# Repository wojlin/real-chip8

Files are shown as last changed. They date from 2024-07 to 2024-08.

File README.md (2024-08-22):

# CHIP8 Machine

## Info:

The CHIP8 Machine is a modern recreation of a vintage 8-bit virtual machine designed to play classic CHIP8 games. Originally developed in the 1970s, CHIP8 was a simple, yet powerful, programming environment that allowed developers to create games and programs with minimal hardware requirements. This project brings the CHIP8 experience to life by building a physical device that runs these vintage games on a custom-made machine, complete with a tactile keyboard, LED display, and an SD card for game storage.

The CHIP8 Machine is perfect for enthusiasts of retro computing and gaming, as well as those interested in DIY electronics projects. It provides a hands-on way to explore the origins of digital entertainment while learning about hardware assembly, 3D printing, and embedded programming.

## Overview:

This guide provides detailed instructions on how to build and set up a CHIP8 machine, including the parts needed, 3D printing instructions, wiring, and software installation.

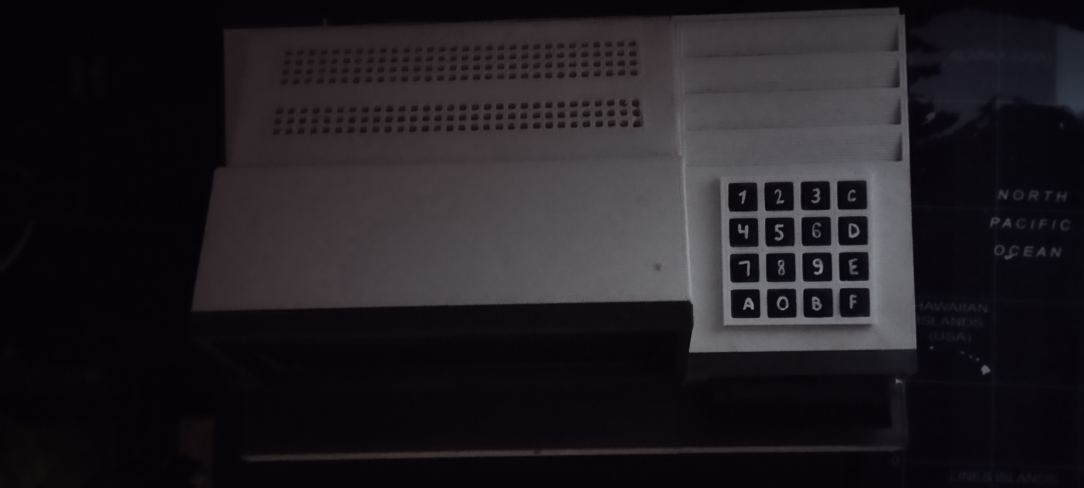
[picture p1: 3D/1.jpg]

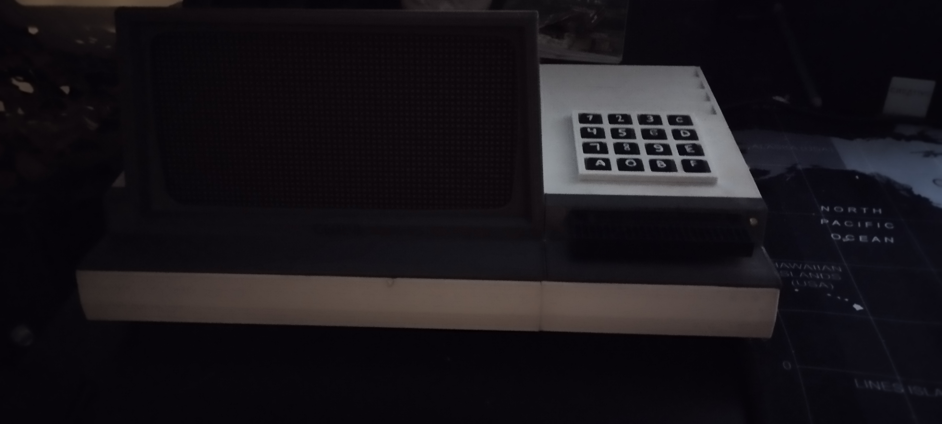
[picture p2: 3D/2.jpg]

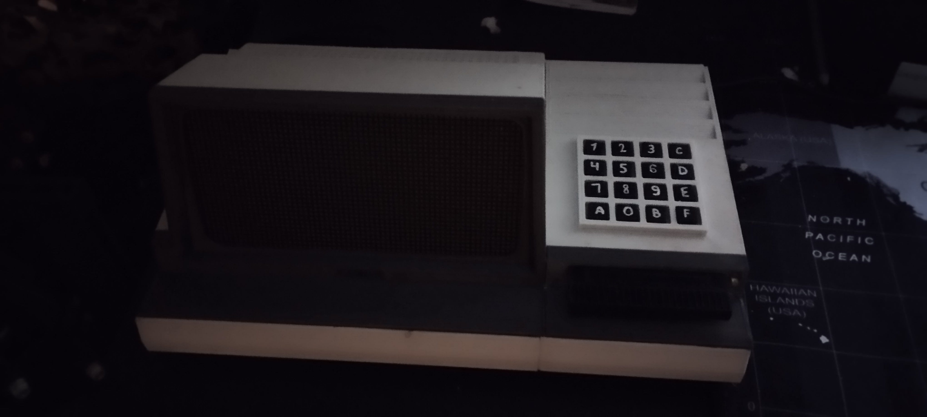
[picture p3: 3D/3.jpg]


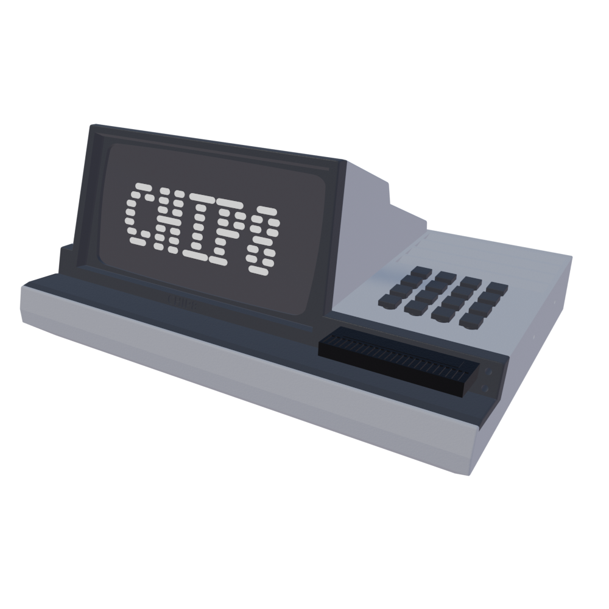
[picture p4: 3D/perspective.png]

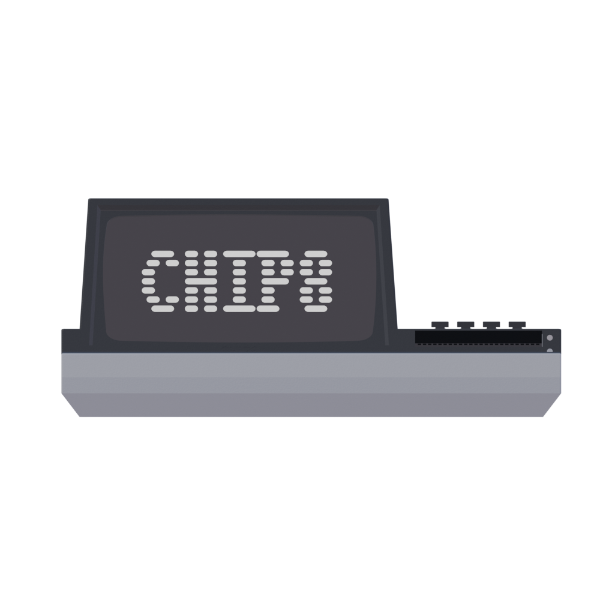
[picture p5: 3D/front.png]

<br>
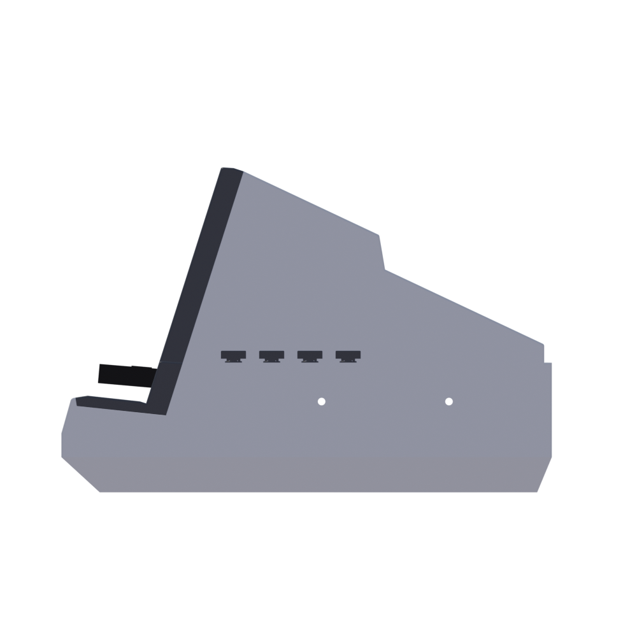
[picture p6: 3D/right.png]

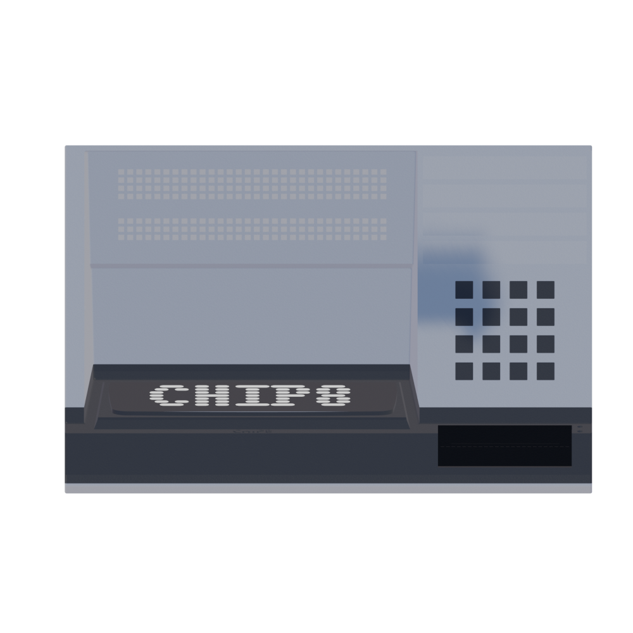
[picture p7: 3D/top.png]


## Documentation:

### Parts List:

You'll need the following components to build the CHIP8 machine:

| Part | Quantity | Link |
|---|---|---|
| 5V 4A power supply | 1 | [Link](https://botland.store/socket-power-supply/8850-power-supply-5v-4a-dc-55-25-plug-5903351242530.html) |
| 12x12mm tact switch with cap | 16 | [Link](https://botland.store/tact-switch/11138-tact-switch-12x12mm-cap-black-5-pieces-5904422307530.html) |
| Micro SD card reader | 1 | [Link](https://botland.store/memory-cards-accessories/8230-micro-sd-card-reader-module-5904422311278.html) |
| 3mm yellow LED | 1 | [Link](https://botland.store/leds/19988-led-3mm-yellow-10pcs-justpi-5904422328764.html) |
| 3mm red LED | 1 | [Link](https://botland.store/leds/19989-led-3mm-red-10pcs-justpi-5904422328771.html) |
| 64x32px 2.5mm Waveshare matrix display | 1 | [Link](https://www.waveshare.com/rgb-matrix-p2.5-64x32.htm) |
| Arduino Mega 2560 | 1 | [Link](https://botland.store/arduino-compatible-boards-dfrobot/2685-dfrobot-mega-2560-v32-compatible-with-arduino-6959420922345.html) |
| Arduino Uno | 1 | [Link](https://botland.store/arduino-basic-boards/1060-arduino-uno-rev3-module-a000066-7630049200050.html) |
| 5mm power switch | 1 | |

**Additional Tools & Materials:**

- Wires
- Soldering tools
- Polishing papers
- Clips
- Screwdriver
- Nail polish remover (optional, for fitting parts)

### Printing & Assembly:

1. **3D Printing:**

   - Find the print files in the `3D/stl` directory.
   - Print the following parts:

    | File               | Color | Quantity |
    |--------------------|-------|----------|
    | display_cover.stl  | Gray  | 1        |
    | keyboard_cover.stl | Gray  | 1        |
    | screw_2x.stl       | Gray  | 2        |
    | screw_4x.stl       | Gray  | 4        |
    | display_mount.stl  | White | 1        |
    | keyboard_mount.stl | White | 1        |
    | keyboard_holder.stl| White | 1        |
    | bottom.stl         | White | 1        |
    | bottom_right.stl   | White | 1        |
    | joiner_3mm_2x.stl  | White | 2        |
    | joiner_5mm_2x.stl  | White | 2        |
    | cartridge.stl      | Black | 1 or more|

    **Required Filament:**

    - White: 0.7 kg
    - Gray: 0.2 kg
    - Black: 0.05 kg

2. **Assembly:**

   - Use the `3D/mode/chip8.blend` file in Blender to visualize the assembly process.
   - Assemble the printed parts (use polishing paper, tools, and nail polish remover for better fitting).
   - Apply a protective coat or paint if desired.
   - Use 4x mm bolts to mount the bottom part with the top parts.
   - Insert the 16x 12x12mm tact switches into the `keyboard_mount.stl` part (use glue to secure them tightly).
   - Place the 3mm yellow LED in the upper hole and the 3mm red LED in the lower hole of `keyboard_mount.stl` (use glue).
   - Insert an OTG USB cable into the cartridge hole in `keyboard_mount.stl` (use glue).
   - Mount the 64x32px RGB matrix display into the `display_mount.stl` (use glue to secure it tightly).
   - Place the SD card reader inside the `cartridge.stl`.
   - Print labels on standard paper and glue them onto the tact switch caps using the following layout:

     | | | | |
     |-|-|-|-|
     |1|2|3|C|
     |4|5|6|D|
     |7|8|9|E|
     |A|0|B|F|

### Wiring:

1. **Arduino Mega Connections:**

    | Pin | Connected To   |
    |-----|----------------|
    | rx3 | Arduino Uno tx  |
    | tx3 | Arduino Uno rx  |
    | A0  | Matrix-A        |
    | A1  | Matrix-B        |
    | A2  | Matrix-C        |
    | A3  | Matrix-D        |
    | 9   | Matrix-OE       |
    | 10  | Matrix-LAT      |
    | 11  | Matrix-CLK      |
    | 24  | Matrix-R1       |
    | 25  | Matrix-G1       |
    | 26  | Matrix-B1       |
    | 27  | Matrix-R2       |
    | 28  | Matrix-G2       |
    | 29  | Matrix-B2       |
    | 32  | Buzzer-sig      |
    | 34  | Power LED+      |
    | 35  | Signal LED+     |
    | 42  | C1              |
    | 43  | C2              |
    | 44  | C3              |
    | 45  | C4              |
    | 48  | R1              |
    | 49  | R2              |
    | 50  | R3              |
    | 51  | R4              |
    | 5V  | Buzzer 5V, Arduino Uno 5V  |
    | GND | Power LED-, Signal LED-, Buzzer GND, Matrix GND1-5, Arduino Uno GND |

2. **Arduino Uno Connections:**

    | Pin | Connected To   |
    |-----|----------------|
    | 5V  | Reader-5V      |
    | GND | Reader-GND     |
    | 10  | Reader-CS      |
    | 11  | Reader-MOSI    |
    | 12  | Reader-MISO    |
    | 13  | Reader-SCK     |
    | tx  | Arduino Mega rx|
    | rx  | Arduino Mega tx|

3. **Other Connections:**

    - Insert the Arduino Mega and Arduino Uno into the `bottom.stl` part.
    - Insert the 5V 4A power supply through the first hole in the `bottom.stl` part.
    - Insert the power switch through the second hole in the `bottom.stl` part.

### Software Installation:

1. **Preparing the SD Card:**

   - Format the SD card to the FAT file system and ensure its label is "chip8". If you want to use a different label, update the name in the `runtime/runtime.py` file.
   - Copy the CHIP8 ROMs you want to use onto the SD card (sample ROMs can be found in the `samples` directory).
   - Ensure that only `.ch8` files are on the card (remove any system-generated files like `trash`, `volume info`, etc.).

2. **Cloning the Repository:**

   - Clone the repository:

     ```bash
     git clone git@github.com:wojlin/real-chip8.git
     ```

3. **Installing Arduino IDE:**

   - Download and install the Arduino IDE from [here](https://www.arduino.cc/en/software).

4. **Uploading the Code:**

   - Plug the machine into the 5V

 4A socket (ensure the power supply is turned on before connecting the USB cable).
   - Open `sd/sd.ino` in the Arduino IDE.
   - Upload `sd.ino` to the Arduino Uno.
   - Open `emulator/emulator.ino` in the Arduino IDE.
   - Upload `emulator.ino` to the Arduino Mega.
   - Unplug the USB cable, mount the bottom part of the machine with the top, and secure it with screws.

### Troubleshooting:

1. Ensure the SD card is formatted to FAT.
2. Verify that the SD card name is "chip8".
3. Check that the files on the SD card are in DOS 8.3 format.

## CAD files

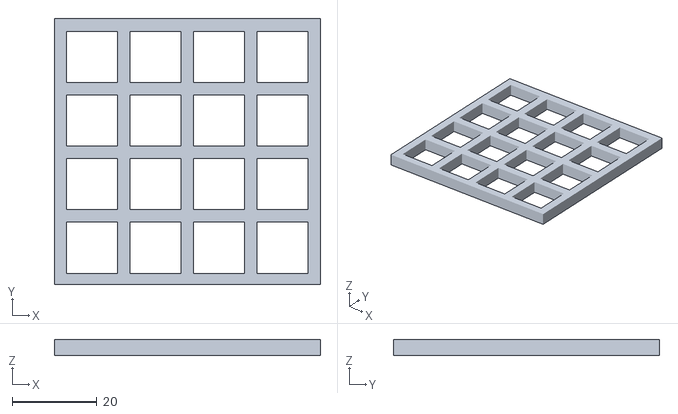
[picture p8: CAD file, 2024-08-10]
3D/stl/keyboard_holder.stl
62.8 x 62.8 x 3.83

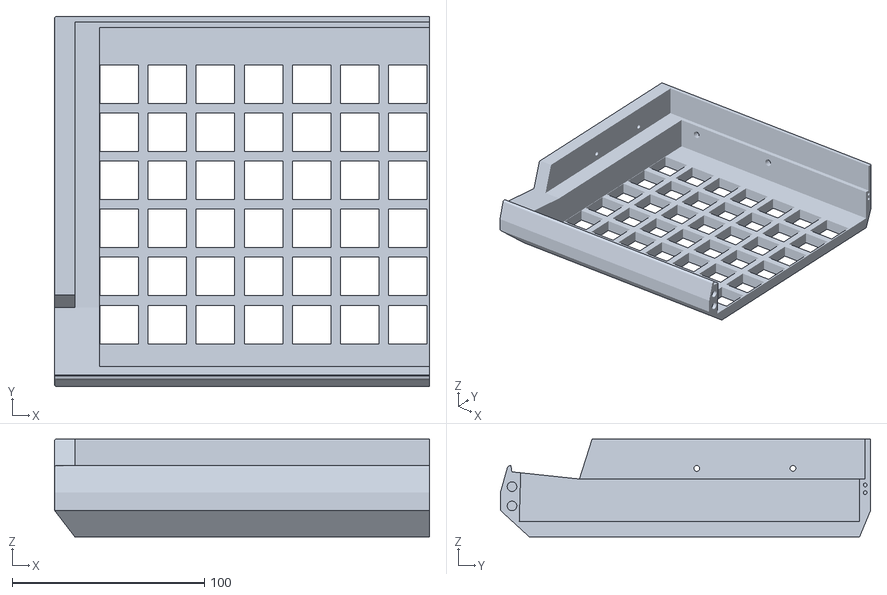
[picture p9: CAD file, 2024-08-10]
3D/stl/bottom.stl
194.9 x 192.5 x 50.9

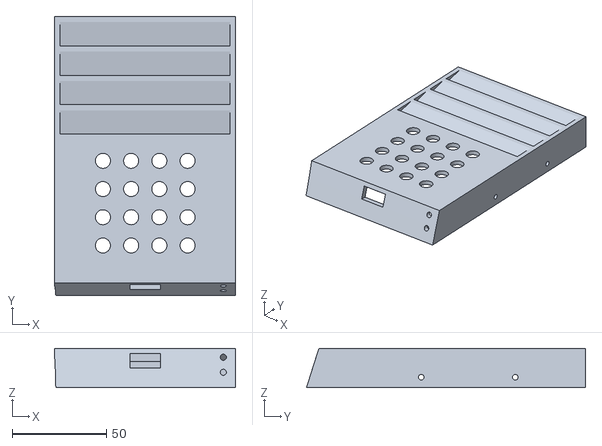
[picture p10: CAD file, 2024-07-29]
3D/stl/keyboard_mount.stl
96.5 x 148.3 x 20.7

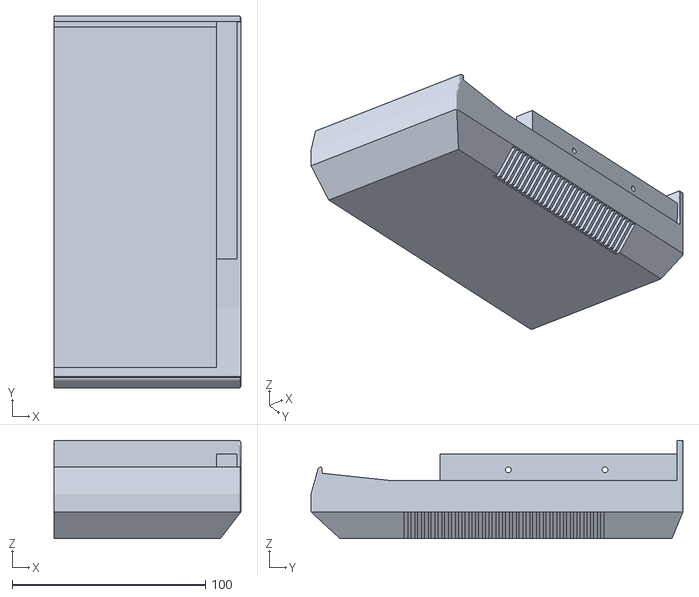
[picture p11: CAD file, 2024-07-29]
3D/stl/bottom_right.stl
96.6 x 192.5 x 50.9

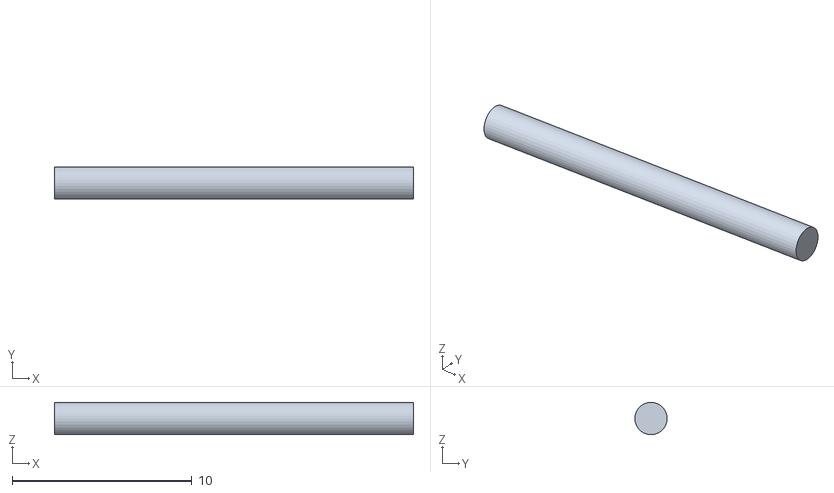
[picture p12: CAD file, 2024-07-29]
3D/stl/joiner_3mm_2x.stl
20.0 x 1.80 x 1.80

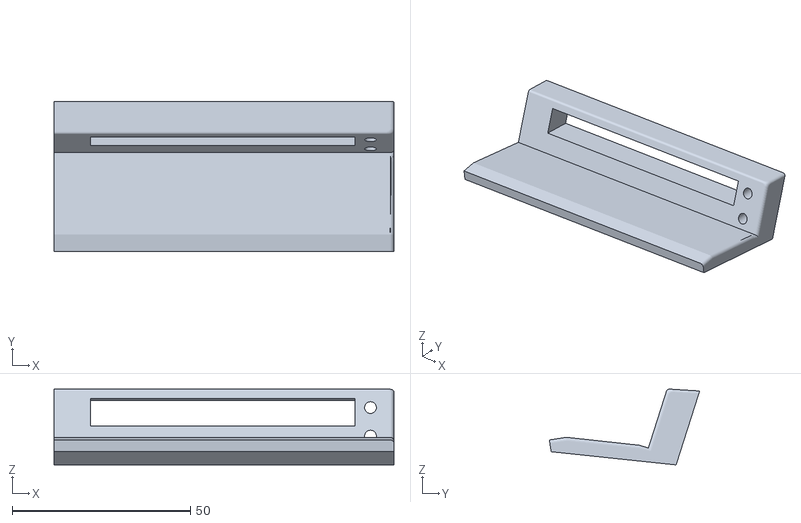
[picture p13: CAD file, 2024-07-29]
3D/stl/keyboard_cover.stl
95.4 x 42.2 x 21.3

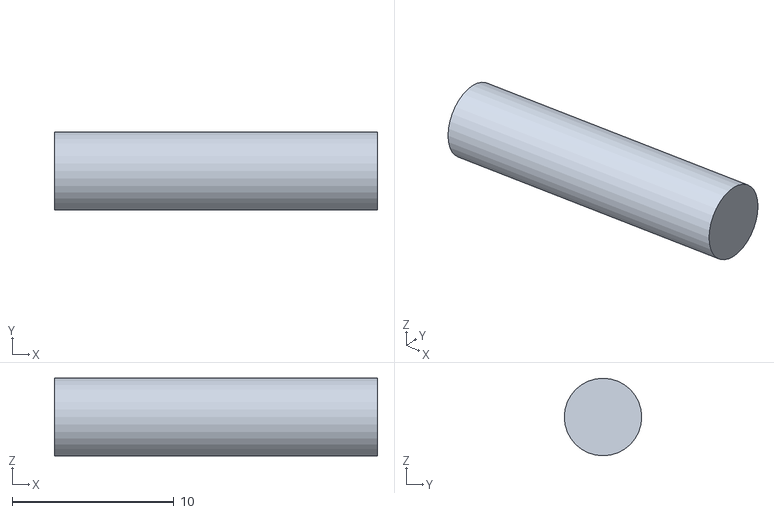
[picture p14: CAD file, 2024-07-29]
3D/stl/joiner_5mm_2x.stl
20.0 x 4.80 x 4.80

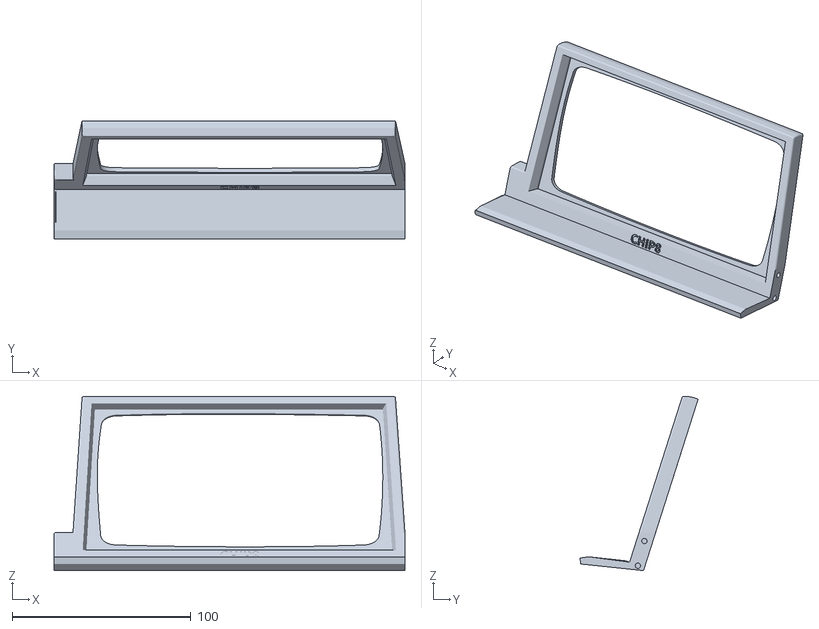
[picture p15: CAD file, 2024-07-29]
3D/stl/display_cover.stl
196.1 x 66.1 x 97.4

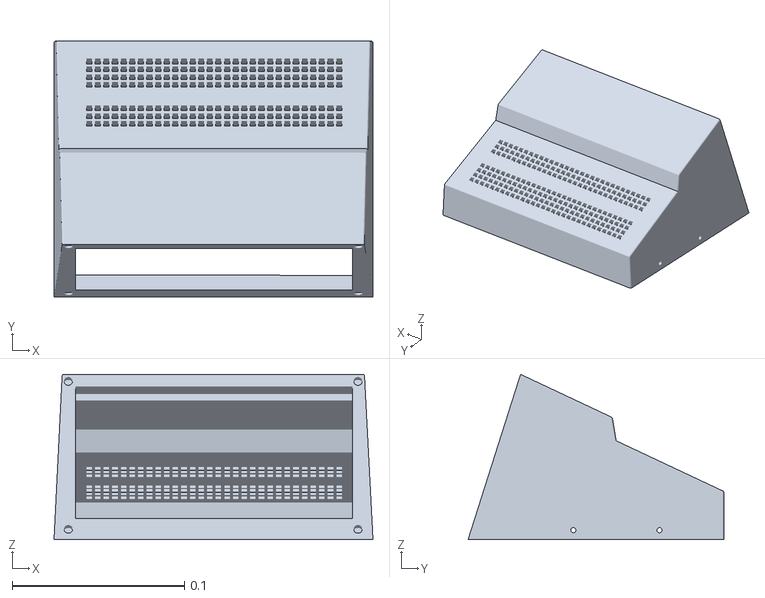
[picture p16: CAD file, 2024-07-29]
3D/stl/display_mount.stl
0.185 x 0.148 x 0.0959

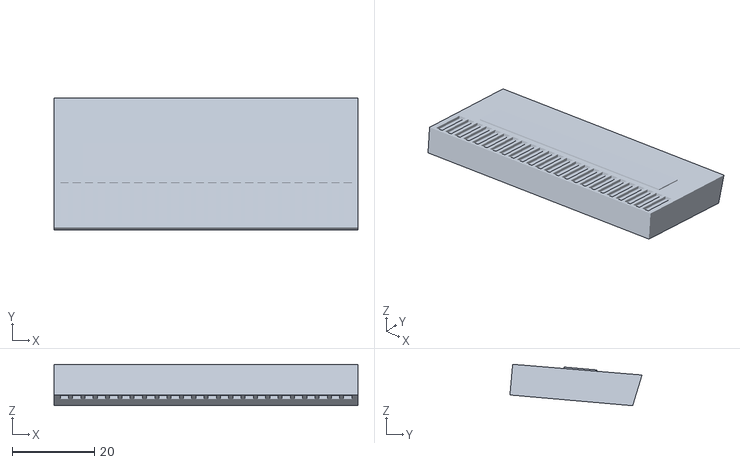
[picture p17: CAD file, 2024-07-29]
3D/stl/cartridge.stl
74.0 x 32.2 x 10.1

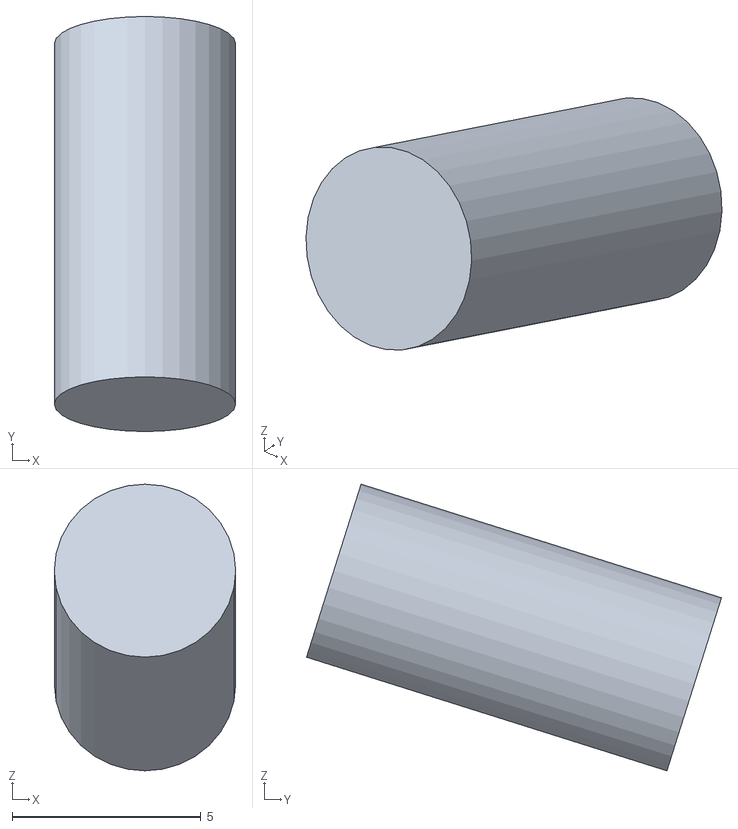
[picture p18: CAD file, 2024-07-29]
3D/stl/screw_4x.stl
4.80 x 11.0 x 7.58

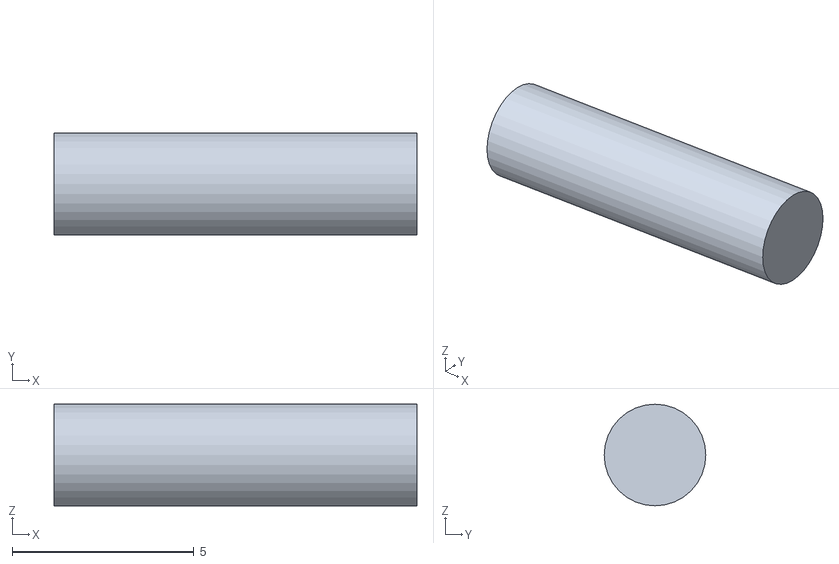
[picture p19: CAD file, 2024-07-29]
3D/stl/screw_2x.stl
10.0 x 2.80 x 2.80

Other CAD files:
3D/model/chip8.blend

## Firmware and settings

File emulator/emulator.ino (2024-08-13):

#include <Arduino.h>
#include <SPI.h>
#include "chip8-keypad.h"
#include "chip8-leds.h"
#include "chip8-buzzer.h"
#include "chip8.h"

#include "RGBmatrixPanel.h"
#include "Adafruit_GFX.h"
#include "bit_bmp.h"
#include "fonts.h"

#include <string.h>
#include <stdlib.h>

#include "Fonts/Picopixel.h"

#define CLK 11 
#define OE   9
#define LAT 10
#define A   A0
#define B   A1
#define C   A2
#define D   A3

RGBmatrixPanel matrix(A, B, C, D, CLK, LAT, OE, false, 64);
GFXcanvas1 canvas(64, 32);

//uint16_t high = matrix.ColorHSV(0,0,0,false);
//uint16_t low = matrix.ColorHSV(1100,155,80,false);

uint16_t high = matrix.ColorHSV(0,0,40,false);
uint16_t low = matrix.ColorHSV(0,0,0,false);

const uint8_t chip_select_reader_pin = 53;
const uint8_t buzzer_pin = 32;
const uint8_t power_led_pin = 34;
const uint8_t signal_led_pin = 35;
const uint8_t input_pins[] = {42, 43, 44, 45}; // Input pins (columns)
const uint8_t output_pins[] = {48, 49, 46, 47}; // Output pins (rows)
const uint8_t num_inputs = sizeof(input_pins) / sizeof(input_pins[0]); // Number of input pins (columns)
const uint8_t num_outputs = sizeof(output_pins) / sizeof(output_pins[0]); // Number of output pins (rows)



uint8_t file_count = 0;
const int BUFFER_SIZE = 200; // Size of the buffer to store received data
char received_data[BUFFER_SIZE]; // Buffer to store received data

#define MAX_FILES 20   // Maximum number of files
#define MAX_FILENAME_LENGTH 50  // Maximum length of each filename

char file_array[MAX_FILES][MAX_FILENAME_LENGTH]; // Adjust the size of the array according to the expected number and size of files


bool sd_plugged = false;
bool file_selected = false;
bool game_finished = false;

int current_file = 0;
int files_in_panel = 4; // Number of filenames that fit into the screen
int program_size;

void(* resetFunc) (void) = 0; //declare reset function @ address 0

void screen_setup()
{
  matrix.begin();
}


void screen_clear()
{
  matrix.fillRect(0, 0, matrix.width(), matrix.height(), low);
}


void draw_title()
{
  screen_clear();
  matrix.setFont(NULL);
  screen_clear();
  matrix.setTextSize(2);     
  matrix.setTextWrap(false); 
  matrix.setCursor(4, 10);   
  matrix.setTextColor(high);
  matrix.println("CHIP8");
}

void draw_pixel(uint8_t x, uint8_t y, uint8_t state)
{
  uint16_t color = (state == 1) ? high : low;
	matrix.drawPixel(x, y, color);
}

void draw_text(String data, uint8_t x, uint8_t y, uint8_t size, const GFXfont *f)
{
    matrix.setFont(f);
	  matrix.setTextSize(size);     
  	matrix.setTextWrap(false); 
  	matrix.setCursor(x, y);   
  	matrix.setTextColor(high);
  	matrix.println(data);
}

void draw_chip8_display(Chip8 *chip8)
{
    for (int y = 0; y < DISPLAY_HEIGHT; ++y) 
    {   
        uint64_t diff = chip8->display[y] ^ chip8->old_display[y];  // XOR to find differing bits
        if (diff)
        {
            for (int x = 0; x < DISPLAY_WIDTH; ++x) 
            {          
                int bit_position = DISPLAY_WIDTH - 1 - x;

                if (diff & ((uint64_t)1 << bit_position)) 
                {
                    // Determine the pixel state in the current display
                    uint8_t state = (chip8->display[y] >> bit_position) & 1;

                    // Draw the pixel with the determined state
                    draw_pixel(x, y, state);
                }
            }
        }
    }
}


int freeMemory() {
  extern int __heap_start, *__brkval;
  int v;
  return (int)&v - (__brkval == 0 ? (int)&__heap_start : (int)__brkval);
}

void draw_selection() {
  Serial.println("#################################");

  screen_clear();

  for (uint8_t i = 0; i < files_in_panel; i++) 
  {
    String line = "";
    if (current_file + i < file_count) {
      line += (i == 0) ? ">" : " ";
      line += String(file_array[current_file + i]);
    }
    Serial.println(line);
    draw_text(line, 2, (i+1)*7,1, &Picopixel);
  }
  Serial.println("#################################");
}

void print_file_list(char** file_list, size_t file_count) {
  Serial.println("Files on SD card:");
  for (size_t i = 0; i < file_count; i++) {
    Serial.println(file_list[i]);
  }
}

void setup() {
  delay(1000);

  // Initialize serial communication for printing
  Serial.begin(9600);
  Serial3.begin(9600);

  // Initialize the keypad
  keypad_init(input_pins, output_pins, num_inputs, num_outputs);

  // Initialize the LED control
  led_control_init(power_led_pin, signal_led_pin);

  // Initialize the buzzer
  chip8_buzzer_init(buzzer_pin);

  // Turn on the Power LED
  led_control_power_led_on();
  
  screen_setup();
  screen_clear();
  draw_title();

  Serial.println("Initialization successful!");
}


void trim(char* str) {
  char* end;

  // Trim leading space
  while (isspace((unsigned char)*str)) str++;

  if (*str == 0) // All spaces?
    return;

  // Trim trailing space
  end = str + strlen(str) - 1;
  while (end > str && isspace((unsigned char)*end)) end--;

  // Null terminate
  *(end + 1) = '\0';
}

// Function to send the "status command" and wait until "plugged" response is received
void handle_status_command() {
  bool status_received = false;
  
  while (!status_received) {
    // Send "status command" to Serial3
    send_command("status");
    
    if (read_serial_response()) {
      trim(received_data);
      if (strcmp(received_data, "plugged") == 0) {
        // Set LED to HIGH state and set status_received to true
        digitalWrite(signal_led_pin, HIGH);
        status_received = true;
      } 
      else if (strcmp(received_data, "unplugged") == 0) {
        // Set LED to LOW state
        digitalWrite(signal_led_pin, LOW);
      }
      Serial.println(received_data);
    }

    delay(1000);
  }
}

// Function to send a command via Serial3
void send_command(const char* command) {
  Serial3.println(command);
}

// Function to read the response from Serial3
bool read_serial_response() {
  static char buffer[BUFFER_SIZE];
  static int buffer_index = 0;
  bool response_complete = false;

  while (Serial3.available()) {
    char incoming_byte = Serial3.read();

    // Check for end of response (newline character)
    if (incoming_byte == '\n') {
      buffer[buffer_index] = '\0'; // Null-terminate the buffer
      // Copy buffer to received_data if it's not empty
      if (buffer_index > 0) {
        strlcpy(received_data, buffer, BUFFER_SIZE);
        buffer_index = 0; // Reset buffer index for next response
        response_complete = true;
      }
      break;
    }

    // Accumulate data into buffer
    if (buffer_index < BUFFER_SIZE - 1) {
      buffer[buffer_index++] = incoming_byte;
    } else {
      // Buffer overflow protection
      buffer_index = 0;
    }
  }

  return response_complete;
}

// Function to handle the "list" command
void handle_list_command() {

  bool list_received = false;
  memset(received_data, 0, BUFFER_SIZE);

  send_command("list");
  while (!list_received) {
    
    delay(10);
    if (read_serial_response()) 
    {
      trim(received_data); // Clean up the received data

      int found = 0;

      for (int i = 0; i < BUFFER_SIZE; i++) {
          if (received_data[i] == '!') {
              found = 1;
              break;
          }
          if (received_data[i] == '\0') {
              break;
          }
      }

      if(found)
      {
        Serial.println(received_data);
        Serial.println("___________________________");
        // Parse the file list
        parse_file_list(received_data);
      
        // Print the file list to Serial Monitor for debugging
        print_file_list();
        return;
      }

      
    
    }
    delay(10);
  }
}

void parse_file_list(const char* list) {
  int char_index = 0;

  // Reset file array and file_count
  for (int i = 0; i < MAX_FILES; i++) {
    file_array[i][0] = '\0'; // Clear all file names
  }
  file_count = 0;

  // Iterate through the list and split filenames based on delimiter '!'
  for (int i = 0; list[i] != '\0'; i++) {
    if (list[i] == '!') {
      if (char_index > 0) {
        file_array[file_count][char_index] = '\0'; // Null-terminate the current filename
        file_count++;

        // Ensure we do not exceed the maximum number of files
        if (file_count >= MAX_FILES) {
          break;
        }

        char_index = 0; // Reset index for the next filename
      }
    } else {
      // Add character to the filename if there's space
      if (char_index < MAX_FILENAME_LENGTH - 1) {
        file_array[file_count][char_index++] = list[i];
      } else {
        // Handle potential filename overflow
        file_array[file_count][MAX_FILENAME_LENGTH - 1] = '\0'; // Null-terminate
        file_count++;

        // Ensure we do not exceed the maximum number of files
        if (file_count >= MAX_FILES) {
          break;
        }

        char_index = 0; // Reset index for the next filename
      }
    }
  }

  // Handle the last filename
  if (char_index > 0 && file_count < MAX_FILES) {
    file_array[file_count][char_index] = '\0';
    file_count++;
  }
}

// Function to print the file list for debugging
void print_file_list() {
  int i = 0;
  while (file_array[i][0] != '\0') {
    Serial.println(file_array[i]);
    i++;
  }
}

int get_file_length(const char* filename) {
  char command[20];
  snprintf(command, sizeof(command), "len!%s", filename);

  send_command(command);
  Serial.print("Requesting length of: ");
  Serial.println(filename);

  // Wait and read the response
  while (!read_serial_response()) {
    delay(100); // Wait until we get the response
  }

  trim(received_data); // Clean up the received data
  int file_length = atoi(received_data); // Convert to integer

  Serial.print("Length of ");
  Serial.print(filename);
  Serial.print(": ");
  Serial.println(file_length);

  return file_length;
}

void fetch_file_into_chip8_ram(const char* filename, Chip8 *chip8) {
  int file_length = get_file_length(filename);
  
  for (int byte_no = 0; byte_no < file_length; byte_no++) {
    char command[30];
    snprintf(command, sizeof(command), "fetch!%s!%d", filename, byte_no);

    send_command(command);
    Serial.print("Fetching byte ");
    Serial.print(byte_no);
    Serial.println("...");

    // Wait and read the response
    while (!read_serial_response()) {
      delay(1); // Wait until we get the response
    }

    trim(received_data); // Clean up the received data
    int number = strtol(received_data, NULL, 16);
    chip8->ram[MEMORY_READ_START + byte_no] = number; // Store byte in CHIP-8 RAM
    
    //Serial.print("Fetched byte: ");
    //Serial.println(received_data); // Print for debugging
    //Serial.println("chip8: " + String(MEMORY_READ_START + byte_no) + " " + chip8->ram[MEMORY_READ_START + byte_no]);
  }

  Serial.println("File loaded into CHIP-8 RAM.");
}

void loop() {
  Chip8 chip8;
  chip8_init(&chip8);
  Serial.println("Waiting for SD card...");

  // phase 1: wait for sd card plug in 
  handle_status_command();
  delay(1500);
  handle_list_command();
  
  Serial.println("Waiting for ROM selection...");

  Serial.println(file_count);
  // phase 2: select file from menu
  while (!file_selected) {
    draw_selection();

    int key = wait_for_key();
    Serial.println(key);
    wait_for_release();
    chip8_buzzer_on();
    delay(50);
    chip8_buzzer_off();

    if (key == 2) { // up key
      current_file--;
      if (current_file < 0) {
        current_file = 0;
      }
    } else if (key == 8) { // down key
      current_file++;
      if (current_file >= file_count) {
        current_file = file_count - 1;
      }
    } else if (key == 5) { // select key
      file_selected = true;
    }
  }

  

  String selected_file = String(file_array[current_file]);
  Serial.println("Selected file: " + selected_file);

  screen_clear();
  draw_text("LOADING...", 2, 12, 1, NULL);

  // phase 3: load program into chip8 memory
  
  fetch_file_into_chip8_ram(selected_file.c_str(), &chip8);

  // phase 4: game loop
  Serial.println("launching game!");
  chip8.display_changed = 1;

  screen_clear();
  int count = 0;
  while(!game_finished)
  {
    long int t1 = millis();

    if(chip8.sound_timer > 0)
    {
      chip8_buzzer_on();
    }
    else
    {
      chip8_buzzer_off();
    }


    if(chip8.display_changed)
    {
    
        draw_chip8_display(&chip8);

      chip8.display_changed = 0;
    }
    

    Opcode opcode = chip8_fetch_opcode(&chip8);
    uint16_t number = opcode.instruction;
    //Serial.println("0x" + String((number >> 12) & 0xF, HEX) + String((number >> 8) & 0xF, HEX) + String((number >> 4) & 0xF, HEX) + String(number & 0xF, HEX));



    int result = chip8_execute_opcode(&chip8, &opcode);
    if(result)
    {
      game_finished = true;
      break;
    }

    long int t2 = millis();
//Serial.print("Time taken by the task: "); Serial.print(t2-t1); Serial.println(" milliseconds");
  }
  Serial.println("game end!");
  delay(1000);
  //phase 5: cleanup memeory and prepere fot the next loop
  resetFunc(); 
}

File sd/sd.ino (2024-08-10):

#include <SPI.h>
#include <SD.h>

const int chipSelect = 10; // Set your SD card chip select pin

bool sdCardInserted = false;

void setup() {
  Serial.begin(9600);
  pinMode(chipSelect, OUTPUT);

  // Initial SD card check
  sdCardInserted = SD.begin(chipSelect);
}

void loop() {
  checkSDCardStatus();  // Continuously check SD card status
  handleSerialCommands(); // Handle serial commands
}

void checkSDCardStatus() {
  // Check if SD card is inserted by attempting to initialize it
  bool currentState = SD.begin(chipSelect);
  
  // Update the state, but do not print status automatically
  sdCardInserted = currentState;
}

void handleSerialCommands() {
  if (Serial.available()) {
    String command = Serial.readStringUntil('\n');
    command.trim();

    if (command.equals("status")) {
      printSDCardStatus();
    } else if (command.equals("list")) {
      listFiles();
    } else if (command.startsWith("fetch!")) {
      fetchByteFromFile(command);
    } else if (command.startsWith("len!")) {
      getFileLength(command);
    }
  }
}

void printSDCardStatus() {
  if (sdCardInserted) {
    Serial.println("plugged");
  } else {
    Serial.println("unplugged");
  }
}

void listFiles() {
  if (!sdCardInserted) {
    Serial.println("unplugged");
    return;
  }

  File root = SD.open("/");
  if (!root) {
    Serial.println("Failed to open directory");
    return;
  }

  root.rewindDirectory();

  String fileList = "";
  File entry;
  while (entry = root.openNextFile()) {
    if (!entry.isDirectory()) {
      fileList += entry.name();
      fileList += "!";
    }
    entry.close();
  }

  if (fileList.length() > 0) {
    fileList.remove(fileList.length() - 1); // Remove the last exclamation mark
  }

  Serial.println(fileList);
  root.close();
}

void fetchByteFromFile(String command) {
  if (!sdCardInserted) {
    Serial.println("unplugged");
    return;
  }

  int firstExclamationIndex = command.indexOf('!');
  int secondExclamationIndex = command.indexOf('!', firstExclamationIndex + 1);

  if (firstExclamationIndex == -1 || secondExclamationIndex == -1) {
    Serial.println("Invalid command format");
    return;
  }

  String filename = command.substring(firstExclamationIndex + 1, secondExclamationIndex);
  String byteNoStr = command.substring(secondExclamationIndex + 1);

  int byteNo = byteNoStr.toInt();

  File file = SD.open(filename);
  if (!file) {
    Serial.println("File not found");
    return;
  }

  if (byteNo >= 0 && byteNo < file.size()) {
    file.seek(byteNo);
    uint8_t byteValue = file.read();
    Serial.print("0x");
    if (byteValue < 0x10) {
      Serial.print("0"); // Add leading zero for values < 0x10
    }
    Serial.println(byteValue, HEX);
  } else {
    Serial.println("Byte out of range");
  }

  file.close();
}

void getFileLength(String command) {
  if (!sdCardInserted) {
    Serial.println("unplugged");
    return;
  }

  int exclamationIndex = command.indexOf('!');

  if (exclamationIndex == -1) {
    Serial.println("Invalid command format");
    return;
  }

  String filename = command.substring(exclamationIndex + 1);

  File file = SD.open(filename);
  if (!file) {
    Serial.println("File not found");
    return;
  }

  Serial.println(file.size());  // Print the file size in bytes
  file.close();
}

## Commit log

2024-07-29 added 3d models
    [bottom.stl, bottom_right.stl, cartridge.stl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]
2024-08-10 working display and sd card
    [bottom.stl, chip8.blend]
2024-08-10 fixed bugs
    [chip8.blend, keyboard_holder.stl]
